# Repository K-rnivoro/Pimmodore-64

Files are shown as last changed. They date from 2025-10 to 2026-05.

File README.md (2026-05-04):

pimmodore small

## A sleek solution for mounting a Raspberry Pi 3B within a Commodore 64 chassis to run emulators or alternative operating systems.

Pimmodore-64 uses the [Keymmodore-64](https://github.com/K-rnivoro/Keymmodore-64) keyboard interface (Pi Pico) so the keyboard is 100% functional. It's a perfect setup for running [BMC64](https://accentual.com/bmc64/), THE Commodore emulator for the Raspberry Pi 3 (any VICE version works well too). 
Functionally speaking, it's like running an original C-64... or C-128, or Plus/4, or PET Graphics, or PET Business. Keyboard will reconfigure itself, allowing you to access all keys, for ANY of the emulated computers.

Also runs perfectly with any Raspberry Pi Operative System, due to having a PC Compatible layout too.

There is also a [modified version of BMC64](https://github.com/slagoela/bmc64) made by Sergio Lagoela, able to automatically switch the Compatibility Mode according the computer being emulated, including the color of the RGB LED.

foto Pimmodore small

Detalle_trasero-removebg-preview

detalle_costado-removebg-preview



To build a Pimmodore-64, you need:

- Build a [Keymmodore-64](https://github.com/K-rnivoro/Keymmodore-64) interface first, including the RGB LED.
- A Raspberry Pi 3B o 3B+.
- A MicroSD Card.
- Any power supply greater than 6VDC, with 15 Watts minimum.
- A Step-down Power converter
- Panel Barrel connector
- Rocker switch
- 2 Joysticks connectors (male DB-9)
- Male 4-pole 3.5mm plug, male RCA and female stereo 3.5mm plug (optional for analog outputs).
- HDMI extension cable.
- 2 USB extension cables (or you can buy a USB 2.0 PC rear panel extension bracket)
- A 3D Printer or a 3D Printing service.
- Dupont cables and connectors.
- Some screws.

Look for the .xlsx file for the detailed BOM.

## Printing the STL Files

The pieces are designed to fit any version of the legendary "Breadbin" Commodore-64 case. It won't fit a C-64C (I don't have one to design it).
The project is 100% reversible, no need to drill, make holes or even glue. It uses the same mount system designed for the original PCB board.

There are two versions, with and without analog outputs (not everybody wants to use an old CRT TV...).

You can use an analog VGA 4:3 monitor (maybe a CRT one for a nice vintage look), with a HDMI to VGA adapter. Remember to buy an adapter with analog audio output in case you don't wire the Pi's analog outputs. Although you will have to create some custom HDMI modes, as explained in [BMC64 page](https://github.com/randyrossi/bmc64)

All pieces are easy to print with a 0.4mm nozzle and a 0.2 mm layer height. For better results, do not flip the pieces, print them as provided. The .3mf file was made for my Bambulab A1, in case you find it useful.
There is no need for «Everywhere» support if you 3D Printer is able to do good «bridging» (most printers do). Just use "Normal" support and «Only from the buildplate».
The only piece who need "Tree" support is the USB Ports cover, and just because of the top lock arm, not for the square holes.
The Pico holder includes a little support, where the board back edge rests, just trim it before placing in.

## Flashing and connecting the Keymmodore-64 interface Pi Pico, to the Pi 3B.

At my project [Keymmodore-64](https://github.com/K-rnivoro/Keymmodore-64) you can find detailed information of how to set up a Raspberry Pi Pico as C-64 keyboard interface. 

Besides the cable connecting the keyboard and the RGB LED, there are also three wires from the Pico, they are used for sensing what type of computer is BMC64 emulating. With this information, the Pico can switch to the corresponding mode, avoiding the manual switch with the C= and Function Keys. As you can see, these three pins have to be connected to GPIO 9, 10 and 11 of the R-Pi 3B.
This is not mandatory, if you do not connect those three pins, you can always use the manual switching, including the "PC Compatible Mode".

### This autoswitch feature works only with the [modified version of BMC64](https://github.com/slagoela/bmc64) made by Sergio Lagoela, it is not included in the oficial release (at least until now).

## Powering the Raspberry Pi

In order to being "agnostic" to the Power Supply, this project uses a Step Down Power Converter, so you can use almost any Power Brick with more than 6V and 15 Watts, a generic 12VDC with 2A will do.
Of course, you need to regulate the Converter BEFORE plug in it to the Raspberry. 5.2VDC will be OK.
Don't try to use a 5VDC power supply directly, the voltage drop of the connector and switch will result in 4.9VDC or less coming into de Pi, therefore the common yellow ligthing bolt sign will appear, and video and audio stuttering will happen, even with "Raspberry Certified Power Supplies". 
Believe me, avoiding the Converter and using a 5VDC Power Supply is not advisable, unless you connect it directly, with no switch in between.

### Remember: Do not plug your Raspberry Pi until you have regulated the Voltage output to 5.2V first!!!!

## Connecting the Joysticks

Unless you have wired the joysticks ports to the Pico interface as mentioned in the Keymmodore-64 project, you can connect them to the Raspberry Pi GPIO pins.

As explained in the [BMC64 website](https://accentual.com/bmc64/), two Atari-like joysticks are supported by the emulator. Here is the wiring according the documentation:



## Enabling the autoswitching feature

In order to the Pico interface to switch between different modes, you need to connect three wires from the GPIOs Pi to the Pico. The GPIOs to be connected are GPIO 9, 10 and 11, as shown in the Keymmodore readme.

Also, add "enable_pimmodore=1" at the beggining of the cmdline.txt file.

Remember this works only for the modified version of BMC64.

## Connecting the analog video and audio outputs (optional)

The Raspberry Pi 3B includes analog video and stereo audio output. For that you need to wire a 4-pole 3.5mm plug, to a female RCA connector for video, and a miniplug stereo female connector for audio.
BMC64 will output NTSC or PAL-B video standard, according what kind of computer are being emulated.
This is optional. You can use your Pimmodore-64 only with HDMI. There is a .stl version or the frame without the analog outputs for that case. 

Keep in mind, the 4-pole miniplug has this (strange) pinout:



## How to set up BMC64 Emulator:

For running BMC64 with the Pi connected to the Pico, you'll need the microSD card with:

1 - The BMC64 Emulator. You can use the modified or the standard BMC64 version, however as explained before, the autoswitching Mode feature won't work in the standard version.

2 - The Kernal ROMs. These are not included in the standard version of BMC64. However you can download from the VICE repository.

3 - The .vkm files in order to have a fully working Keyboard matching all 8-bit emulated computers. Replace the original "positional" .vkm with the new ones.

4 - Enter BMC64 Menu (as explained below), go to "Keyboard" and and change from "Symbolic" to "Positional".

5 - Go to GPIO and check Config is set in "#1 (Nav+Joy)".

6 - Go to Joysticks Menu. If you have wired the joystick ports to the Pi's GPIOs, go to "Joyport" and select GPIO Bank 1 and GPIO Bank 2 for Port 1 and Port 2 respectively. If you have wired the ports to the Pico instead, select Keyset 1 and Keyset 2 and then configure those Keysets below in the same menu.

I strongly recommend to read the [BMC64 readme](https://github.com/randyrossi/bmc64/blob/master/README.md) file for a good understanding of the BMC64 options.

In order to make the whole process easier, I've uploaded a complete version of Lagoela's BMC64 V4.2 autoswitching version, already configured, including the Kernal ROMS and the .vkm files. Joysticks are set as Pi's GPIOs.

I've added HDMI modes for 1080p (HD) monitors and TVs. Both 60Hz for NTSC emulation, and 50 Hz for PAL emulation. I can't tell for every monitor or TV to work OK with 50 Hz, mostly in NTSC-only regions.

Just download, unzip, copy to a FAT32 formatted microSD and boot. 

### Entering the BMC64 Emulator Menu

For entering the BMC64 Menu you need to press CTRL+F7. In PC Compatible Mode (green LED) just press those keys. However, once you are in any Emulator Mode, you can press C= and F7 key for entering the Menu. While browsing the Menu, press Left Arrow Key to go back or exit the Menu. Remember to save the changes before exiting. 

## How to test your keyboard and Joysticks.

I strongly suggest you to use the [Anykey program by T-Pau](https://github.com/T-Pau/Anykey). It has separate versions of programs for every 8 bit Commodore Computer. Very useful. 

## Manual (en español).

I've written a short manual in spanish you can find useful to print (or translate).

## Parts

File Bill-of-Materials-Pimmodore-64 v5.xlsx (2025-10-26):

Description | Item | Quantity | Comments | Suggested Link
Raspberry Pi and SD Memory Card | Raspberry Pi 3B o 3B+ | 1 | R-Pi 3A+, 4 and 5 are not compatible
 | MicroSD 8GB o bigger | 1 | You can buy any MicroSD (compatible with R-Pi)
Keyboard interface | Raspberry Pi Pico (Pins not soldered) | 1 | No need for Pico W, no WiFi suppported | https://www.amazon.com/Raspberry-Pi-Pico/dp/B09KVB8LVR?s=electronics&sbo=RZvfv%2F%2FHxDF%2BO5021pAnSA%3D%3D
 | Male Header 40 Pins Strip (10pcs) | 2 | If not provided with the Board | https://www.amazon.com/MCIGICM-Header-2-45mm-Arduino-Connector/dp/B07PKKY8BX?s=electronics
 | USB-A to Micro-USB Cable | 1 | Generally provided with the Board | https://www.amazon.com/StarTech-com-Mobile-Charge-Micro-Cable/dp/B00MTZUWO8?s=electronics (https://www.amazon.com/gp/product/B00VUIUAN8/ref=ppx_yo_dt_b_asin_title_o02_s04?ie=UTF8&psc=1)
Connectors for Atari/Commodore Joysticks (x2) | Panel mount DB-9 male connectors | 2 |  | https://www.amazon.com/Computer-Connector-Adapter-Connectors-Accessories/dp/B07BQHMKG2?s=electronics
Cables to connect Joysticks ports | Female to female Dupont Cables (40cm) | 1 |  | https://www.amazon.com/EDGELEC-Breadboard-1pin-1pin-Connector-Multicolored/dp/B07GD312VG?s=industrial
RGB LED | RGB translucid LED common anode (do not buy transparent, the effect won't be the same) | 1 | Replaces the original red LED of the C-64 | https://www.amazon.com/EDGELEC-Tri-Color-Multicolor-Diffused-Resistors/dp/B077XD5T8P
 | LED Holder (in case your original holder broke) | 1 |  | https://www.amazon.com/Honbay-Pieces-Plastic-Mounting-Holders/dp/B01LX8JVG7?s=hi
 | Resistor 10KOhms 1/4 Watt | 4 |  | https://www.amazon.com/DIYElectronic-100pcs-Resistor-Tolerance-Precision/dp/B085HNCSS2?s=electronics
Power Supply | Monopole Switch KCD11 (15x21mm) | 1 | Any 15x21 rocker switch (not 10x15 !!!) | https://www.amazon.com/dp/B07Y1GDRQG?tag=picclick0f-20&linkCode=osi&th=1&psc=1
 | Panel mount Barrel Jack Female Connector 5.5x2.1 (same diameter than PS) | 1 | Match Barrel jack diameter of male and female | https://www.amazon.com/MEETOOT-5-5mm-Female-Socket-Electrical/dp/B09JP19XKP
 | Power Supply 12 Volt 4A (with barrel jack connector) | 1 | Any PS with voltage larger than 5V and 15 W should be enough | https://www.amazon.com/Universal-Converter-Transformer-100-240v-5-5x2-5mm/dp/B0D7L6942H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
 | Micro USB Male Plug Cable 30cm | 1 | You can solder a cable to the solder pads of the R-Pi Micro-USB instead | amazon.com/5-5x2-1mm-Converter-Transformer-Surveillance-External/dp/B07GFFG1BQ/ref=sr_1_1_sspa?crid=3UDEQMWS0KRR&dib=eyJ2IjoiMSJ9.Jy4yLGlsxsQ4j2ruSPPP8sdGo7_MV8C27PGwQ5XaYyEBErkYJvKLfZZ7UJ7MP0FWe_UaMuDnNnGXSPtg6wWL7ohDcMkxkhlv5GtmMD71MzzAONcIz2AFMGybRUSKaYgY0Y9KSNYj8d48Psf6un8UmwB007EnYF5RpTr4eAnhMsge7wbBooHIzdoKAiGypMEVLWQ2Jy3-6b08VHExzoYgdxnmD9qh2RuqkQguvAqEjMM.FiBuLPDYSJGmZFBYhS1RPDbl4WgnXozUFemd2zVKEag&dib_tag=se&keywords=12V+Power+Supply+5.5x2.1mm&qid=1761494423&sprefix=12v+power+supply+5.5x2.1mm%2Caps%2C266&sr=8-1-spons&sp_csd=d2lkZ2V0TmFtZT1zcF9hdGY&psc=1
 | Step Down converter | 1 | Adjust output to 5.2V BEFORE connecting it to the R-PI | https://www.amazon.com/XL4005-Adjustable-Supply-Lithium-Charger/dp/B093L9Y6G6?s=electronics
USB Panel Mount extension cables (x2) | Panel Mount USB extension cables (40mm or larger) | 2 | Only panel mount cables | https://www.amazon.com/StarTech-com-USBPNLAFAM2-Extension-Female-Adapter/dp/B00MOENR78?s=electronics
HDMI extension cable. | Panel mount HDMI Cable (1ft) | 1 | If not this model, use alternate (universal) 3D Cover | https://www.amazon.com/gp/product/B01MXD15TE/ref=ppx_yo_dt_b_asin_title_o04_s02?ie=UTF8&psc=1
Optional Analog Video (Composite) and Audio (stereo) Outputs | Four pole male Miniplug 3.5mm | 1 | Only 4 pole miniplug connectors | https://www.amazon.com/gp/product/B077XVDQ5R/ref=ppx_yo_dt_b_asin_title_o04_s02?ie=UTF8&psc=1
 | Panel mount female Miniplug 3.5mm stereo | 1 |  | https://www.amazon.com/gp/product/B01C773OP6/ref=ppx_yo_dt_b_asin_title_o00_s02?ie=UTF8&psc=1
 | Panel mount RCA female connector | 1 |  | https://www.amazon.com/Conwork-Connector-Chassis-Amplifier-Terminal/dp/B07DB36TY9?s=electronics

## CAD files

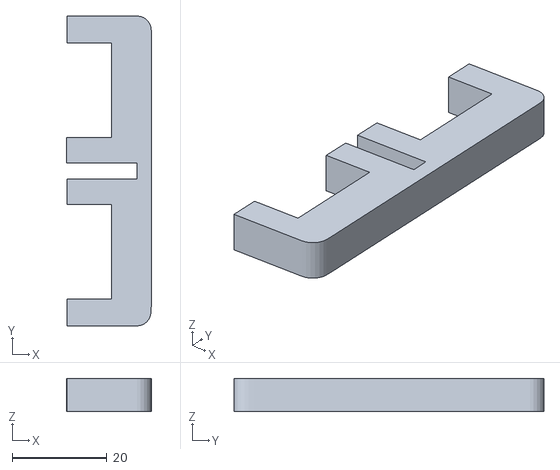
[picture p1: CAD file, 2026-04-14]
STL Files/Pimmodore v45 Joystick ports retainer.stl
17.8 x 65.3 x 7.00

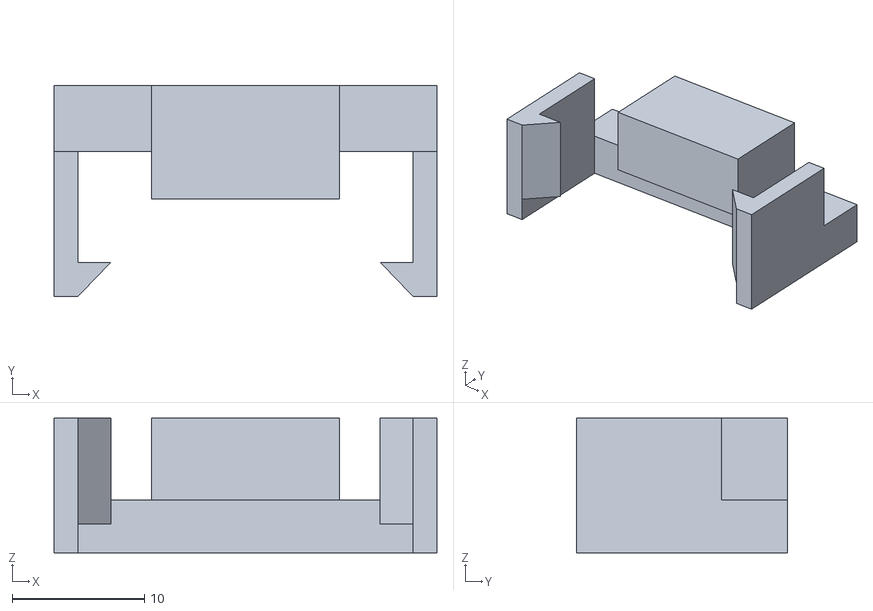
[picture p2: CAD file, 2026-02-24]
STL Files/Pimmodore v45 Pico retainer.stl
29.0 x 16.0 x 10.2

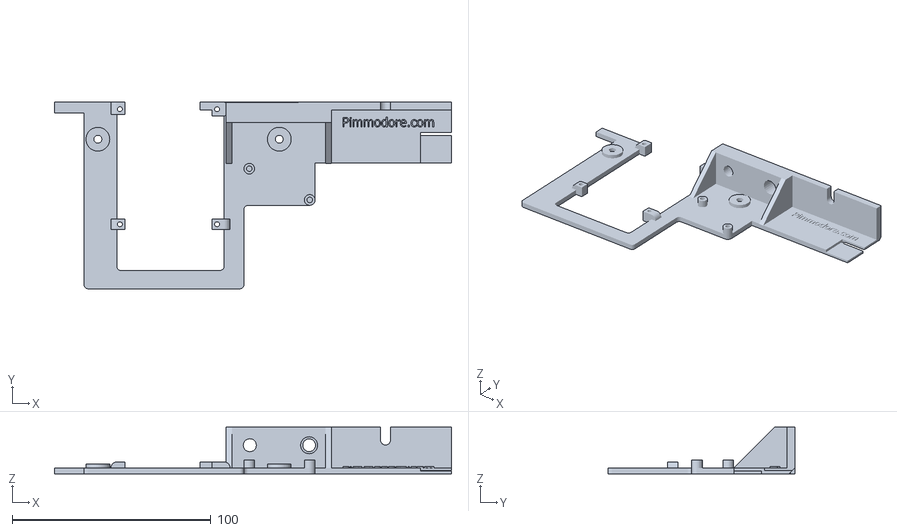
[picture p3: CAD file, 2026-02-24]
STL Files/Pimmodore v45 left frame with analog outputs.stl
200.0 x 94.0 x 23.5

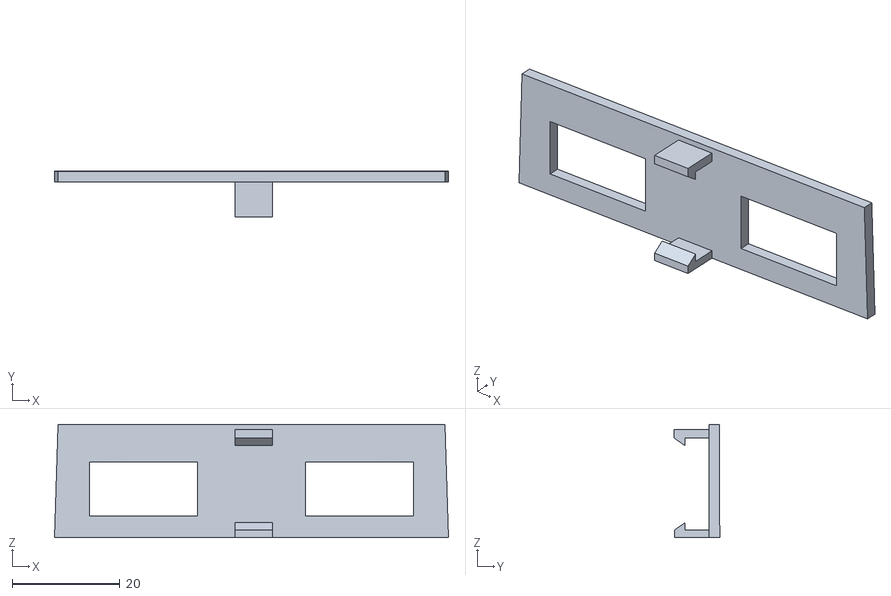
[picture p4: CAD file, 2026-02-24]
STL Files/Pimmodore v45 USB Cover.stl
73.0 x 8.44 x 21.0

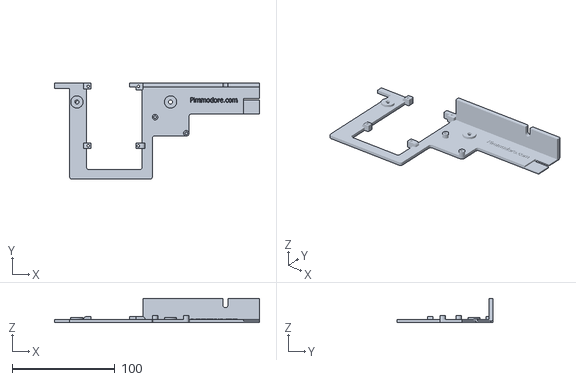
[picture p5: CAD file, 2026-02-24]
STL Files/Pimmodore v45 left frame without analog outputs.stl
200.0 x 94.0 x 23.5

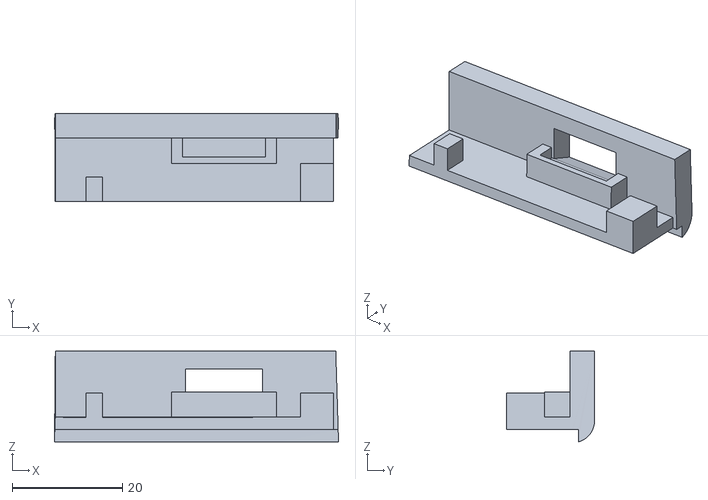
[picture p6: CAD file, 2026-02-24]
STL Files/Pimmodore v45 SD Card.stl
51.5 x 16.0 x 16.5

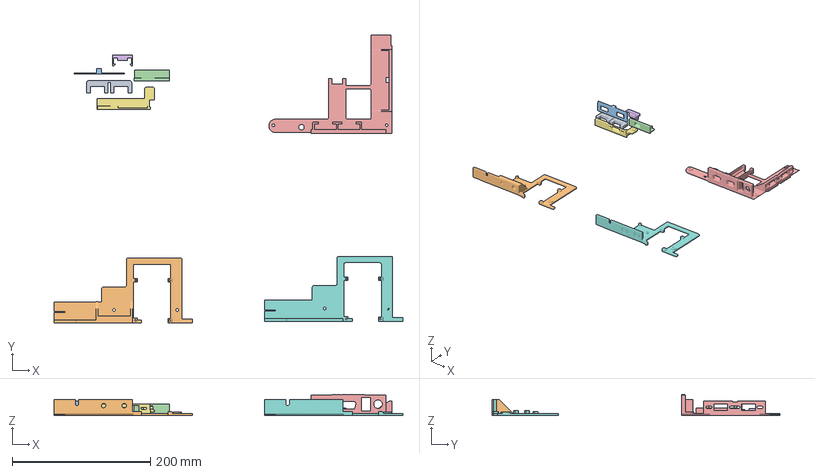
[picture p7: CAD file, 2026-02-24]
STL Files/Pimmodore.3mf
504.5 x 416.1 x 30.6 mm
Pimmodore v45 joystick port retainer.stl
Pimmodore v45 left frame with analog outputs.stl
Pimmodore v45 USB Cover.stl
Pimmodore v45 SD Card.stl
Pimmodore v45 right frame for Pico.stl
Pimmodore v45 Pico retainer.stl
Pimmodore v45 HDMI generic.stl
Pimmodore v45 left frame without analog outputs.stl

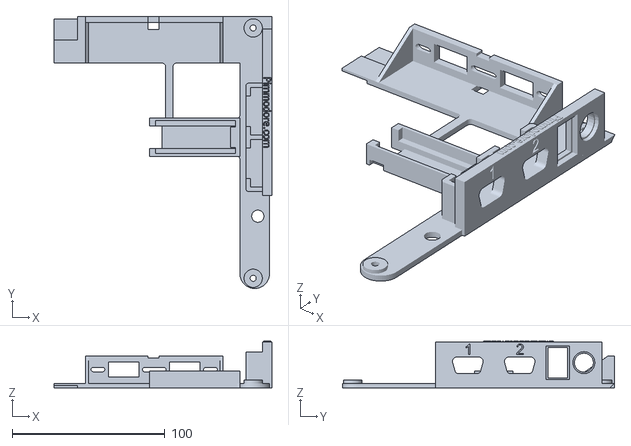
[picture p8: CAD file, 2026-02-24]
STL Files/Pimmodore v45 right frame for Pico.stl
142.4 x 178.0 x 30.6

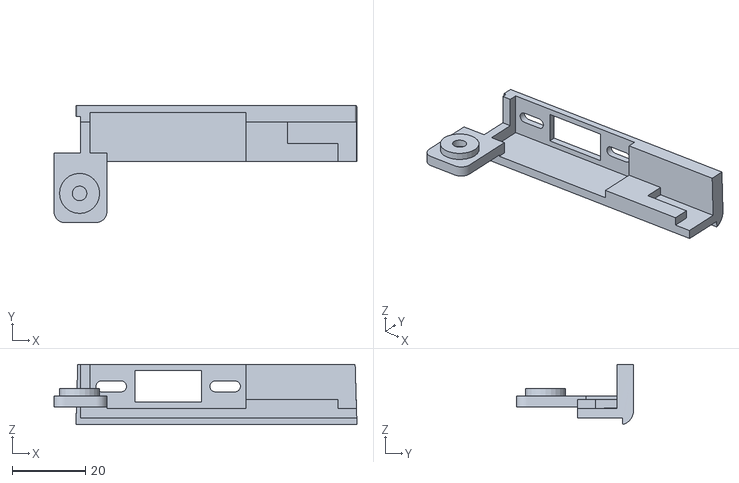
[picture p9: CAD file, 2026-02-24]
STL Files/Pimmodore v45 HDMI generic.stl
83.0 x 32.1 x 16.5

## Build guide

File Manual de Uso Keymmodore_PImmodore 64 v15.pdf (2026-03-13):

www.pimmodore.com

www.pimmodore.com | 2

## Pimmodore-64 y el emulador Bare Metal Commodore 64

El desarrollo Pimmodore-64 está basado en el emulador “Bare Metal Commodore-64” (BMC64) desarrollado por Randy Rossi (https://accentual.com/bmc64/) para la Raspberry Pi 3. Es capaz de emular varias máquinas Commodore de 8 bits: VIC-20, C-64, C-128, la serie C-264 (como la Plus/4 y C-16) y PET (tanto con teclado Graphics como Professional). Además es capaz de emular cada una de ellas tanto en sus versiones NTSC como PAL-B.

Gracias a la colaboración de Sergio Lagoela, existe una versión customizada del BMC64 para la Pimmodore-64, que agrega una funcionalidad que realiza el cambio automático del Modo del Teclado, como se verá mas adelante. Mas información de dicha versión aquí: https://github.com/slagoela/bmc64.

Pimmodore-64 es en realidad, un derivado de la interfase “Keymmodore-64”, la cual convierte el teclado de nuestra C-64 en un teclado USB que pueda ser usado por cualquier computadora o host compatible con dicha norma. Para eso se utiliza una placa Raspberry Pi Pico (no confundir con la Raspberry Pi 3) con una versión personalizada del firmware “Quantum Mechanical Keyboard” (QMK), muy utilizado en teclados gamers.

## Detalle técnico y uso de archivos de configuración “.vkm” para la

emulación.

Pimmodore-64 (o mas bien Keymmodore-64), se basa en dos acciones que son transparentes al usuario:

1. El remapeo del teclado para cada Modo de Compatibilidad de cada una de las maquinas a emular, esto se hace cada vez que se selecciona un Modo de Compatibilidad particular, que se encuentra indicado por el color del LED.
2. La interpretación o conversión de un teclado físico al teclado real de la computadora a emular, lo cual se realiza a través de los archivos “.vkm” con los que cuentan los emuladores basados en VICE (como BMC64 y Combian). Esto lo realiza automáticamente el emulador para cada máquina a emular, leyendo el “.vkm” asociado a dicha máquina.

Es importante entonces, que el emulador a utilizar se encuentre correctamente configurado, y con los archivos “.vkm” correspondientes para cada computadora a emular.

## Emulación de diferentes modelos de computadoras de 8 bits de

Commodore.

Pimmodore-64 es capaz de emular 6 tipos diferentes de computadoras Commodore de 8 bits, a saber:

- Commodore-64.
- Commodore VIC-20.
- Commodore línea 264: Commodore Plus/4, Commodore-16 y Commodore 116.
- Commodore-128.
- Commodore PET Graphics.
- Commodore PET Business.

Además, como se comenta mas adelante, es capaz de utilizarse como un teclado estándar para PC.
Funcionalidad del LED RGB.

Este LED RGB de la Pimmodore-64, le informará que tipo de computadora está siendo emulada, a saber:

Modo Commodore-64, VIC-20, C-16, C-116 y Plus/4.
El Modo Commodore-64, VIC-20, Commodore-16, 116 y Plus/4 Compatible, está diseñado para obtener el 100% de compatibilidad en la distribución de teclas que otorgan tanto los Emuladores de Commmodore-64, VIC-20 y la familia de computadoras Commodore 264. El LED quedará encendido en color rojo, excepto al presionar la tecla C= que se volverá blanco.

### Modo Commodore-128

El Modo Commodore-128, tiene la misma funcionalidad para la C-128 y sus variaciones, incluyendo el teclado numérico y las teclas exclusivas del modelo. El LED se quedará encendido en color azul.

Modo Commodore PET Graphics.
El Modo Commodore PET Graphics Compatible otorga la misma compatibilidad para los emuladores de la familia de Commodore PET. En este caso incluye tanto los caracteres como los gráficos PETSCII que incluía el teclado de la primer versión de la PET llamado comúnmente “Graphics”. Los modelos de PET Graphics son los 2000, 3000 y 4000 (sin B). El LED se quedará encendido en color amarillo

Modo Commodore PET Business.
El Modo Commodore PET Business Compatible, hace lo mismo con la posterior versión de teclado de las PET, conocido comúnmente como “Business”, los cuales en vez de caracteres gráficos PETSCII, contaban con letras mayúsculas y minúsculas. Los modelos de PET Business son la 3000B, 4000B y los modelos 8000 que contaban con 80 columnas. El LED se quedará encendido en color violeta.

Modo PC Compatible.
El Modo PC Compatible es el modo en el que la Pimmodore-64 se utiliza cuando no se encuentra ejecutando el emulador BMC64. Es el que permite utilizar el teclado con cualquier Sistema Operativo, sea de Raspberry, PC, Apple e inclusive Android. Funciona como cualquier teclado USB, con una distribución del tipo “Estados Unidos (US)”. Cuando el teclado se encuentra en el Modo PC Compatible, el LED se muestra en color verde.

Modo de Funciones especiales y Conmutación.

En cualquier de los modos, la tecla C=, pasa a ser una tecla de Modificación o Función (Fn). El LED de la Pimmodore-64 tomará un tono blanco indicando que es posible acceder a otras funcionalidades de acuerdo a la computadora que se esté emulando. Además, permite conmutar manualmente entre diferentes modos de compatibilidad como se ve seguidamente.

Conmutación manual de los modos de Compatibilidad.

Si bien Pimmodore-64 integra una funcionalidad para conmutar automáticamente, es posible realizar la conmutación manualmente para cuando se utiliza en un entorno diferente al emulador BMC64.

Para ello, se utiliza la tecla Commodore (C=) en conjunto con las teclas de Función F1 a F5. Al presionar dicha tecla, el LED tomará un color blanco.

En el esquema siguiente puede identificarse las teclas que permiten cambiar los Modos de Compatibilidad.

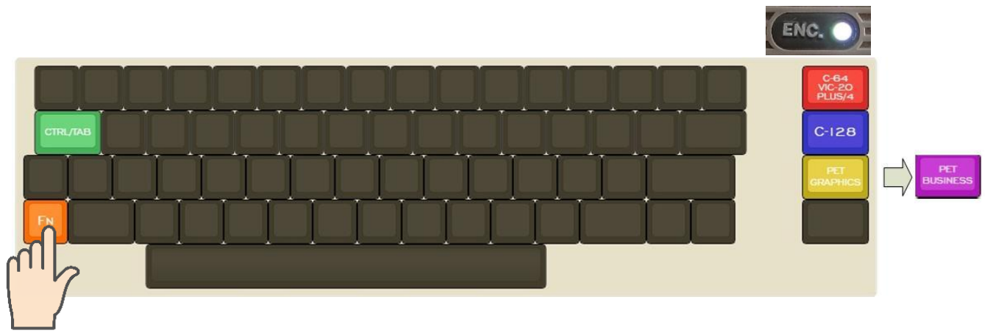
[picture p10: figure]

- Modo C-64, VIC-20, C-16, C-116 y Plus/4: Mantenga presionada la tecla Fn (C=), y presione la tecla F1.
- Modo C-128: Mantenga presionada la tecla C=, y presione la tecla F3.
- Modo PET Graphics: Mantenga presionada la tecla C=, y presione la tecla F5.
- Modo PET Business: Una vez seleccionado el Modo PET Graphics, presione nuevamente la tecla C=, y F5.
- Modo PC: Desde cualquier Modo de los anteriores, presionando C=, y la tecla CONTROL, se vuelve al Modo PC.

Nota importante: Siempre debe volverse al Modo PC primero, antes de cambiar a otro modo. No es posible cambiar entre los diferentes modos de emulación, excepto de PET Graphics a PET Business. Tampoco es posible pasar directamente del Modo PC al PET Business.

## Distribución y funciones de los Modos de Compatibilidad

### Modo compatibilidad con C-64 y VIC-20

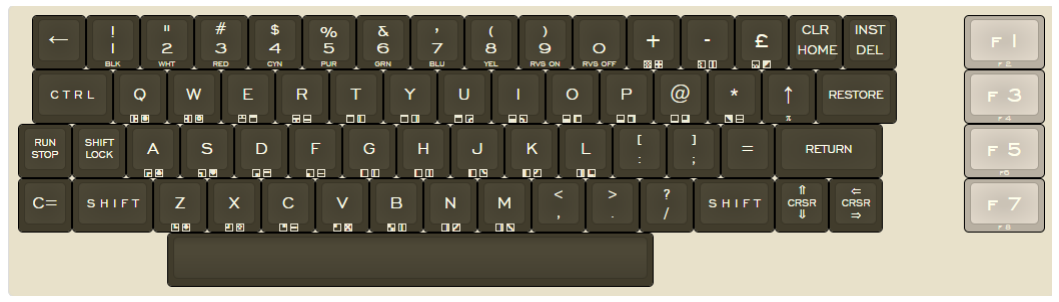
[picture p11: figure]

En este modo, el teclado se comporta exactamente igual que en su equipo original, incluyendo los símbolos sobre el frente de las teclas que se accede presionando SHIFT o C=.

Este modo debe seleccionarse cuando se ejecuta un emulador, para asegurar la compatibilidad total del software que se está ejecutando.

Recordar que para que funcione correctamente, los emuladores deben tener la configuración de teclado en modo “Positional” como se explicó anteriormente.

Se puede volver al Modo compatible con PC, presionando la teclas C= y luego CTRL.

Modo compatibilidad con Plus/4 y C-16.

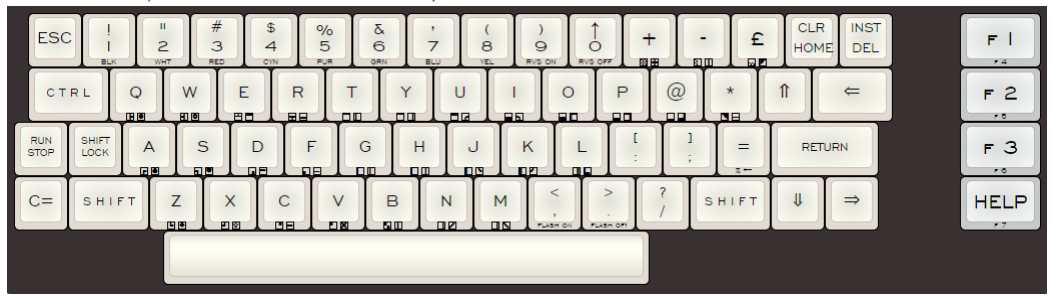
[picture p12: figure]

Si bien los teclados de C-64 y C-16 son físicamente similares, la posición y función de algunas teclas son diferentes, como son las teclas de cursor por ejemplo. Con el objetivo de facilitar su uso, se mantuvo la posición original del teclado de C-64 en aquellas teclas que fuera posible, y se redistribuyeron aquellas diferentes. De esta manera se obtiene la misma funcionalidad que el teclado de C-16 sin tener que recordar su posición original. Los cambios son los siguientes:

- La ubicación de las teclas – (menos), * (asterisco), + (suma), = (igual), £ (pound), y CLEAR/HOME mantienen la posición original de la C-64.
- Se utilizan las teclas originales de cursor de la C-64 para los cursores ↓ (abajo) y → (derecha). A diferencia de la C-64, SHIFT no invertirá la dirección de las mismas.
- Las teclas ↑ y RESTORE funcionan como cursores ↑ (arriba) e (izquierda) respectivamente.
- Las teclas F1, F3, F5 y F7 son F1, F2, F3 y HELP respectivamente, incluyendo el cambio de la funcionalidad a F4, F5, F6 y F7 si se las presiona con SHIFT.

Vale mencionar que tanto en la C-16 como la Plus/4, era necesario presionar las teclas SHIFT o C= para acceder a los caracteres frontales de las teclas (excepto los cursores).

Recordar que para que funcione correctamente, los emuladores deben tener la configuración de teclado en modo “Positional” como se explicó anteriormente.

Presionando la tecla C= junto con CTRL, la distribución vuelve al modo de PC Compatible.

Modo compatibilidad con Commodore-128.

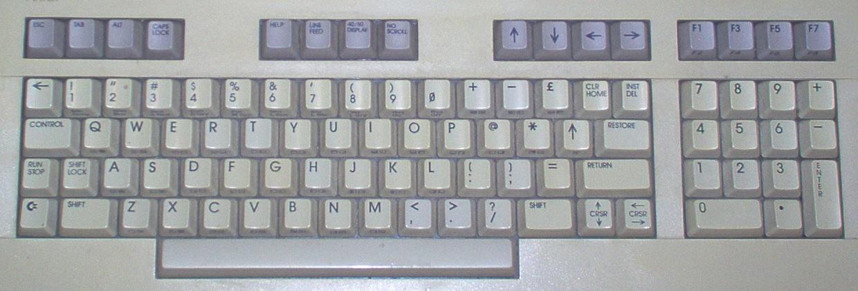
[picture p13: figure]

La C-128 era básicamente un teclado de C-64 ampliado, por lo que la mayoría de sus teclas funcionarán de la misma manera que la C-64.

Teclas especiales de la C-128
Para acceder a las teclas particulares de la C-128 como las de la primera fila y el teclado numérico, se utiliza la tecla de SHIFT Derecho. Al presionarla, el LED se pondrá de color cyan y varias teclas de la Pimmodore se remapean como se muestra en el siguiente esquema.

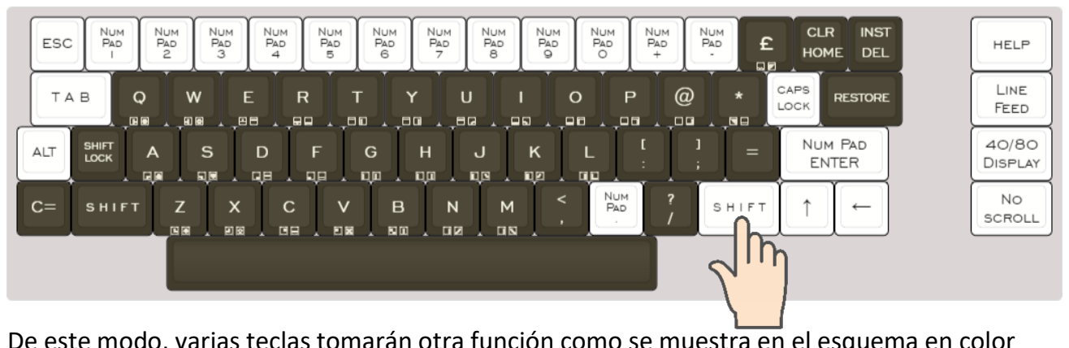
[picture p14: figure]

De este modo, varias teclas tomarán otra función como se muestra en el esquema en color claro.

Por ejemplo, al presionar SHIFT Derecho y las teclas de número, en vez de obtener los signos de puntación de las mismas, obtendrá los números pero que corresponden a las teclas físicas del teclado numérico de la C-128.

Asimismo, podrá acceder a las teclas del teclado numérico, TAB, ALT, CAPS LOCK, etc, las cuales son mapeadas a diferentes teclas como muestra el diagrama.

El resto de las teclas funcionarán indistintamente ya sea con el SHIFT Izquierdo o Derecho.

Recuerde siempre que para salir del Modo C-128 y volver al Modo PC, debe presionar la tecla C= junto con CTRL.

Modo compatibilidad con Commodore PET.
Pimmodore-64 es completamente compatible con la línea de computadoras PET de Commodore. Debe tenerse especial cuidado de que existían dos tipos de teclados de dichas computadoras, la original conocida como teclado “Graphics”, y la posterior con teclado tipo “Business”.

Es importante saber cuales modelos de PET corresponden a cada teclado. En términos generales los modelos 2000, 3000 y 4000 corresponden al teclado Graphics (exceptas aquellas que terminan el B como la 4032B). Los modelos siguientes comenzando por los 8000 con displays de 80 columnas, corresponden a teclados Business.

Como se explicó mas adelante, para utilizar el modo PET Business, primero debe seleccionarse el modo PET Graphics con C= + F5 lo que pondrá el LED color amarillo, luego soltar ambas teclas, y volver a presionar C= + F5 lo que pasará el LED al color violeta indicando el modo PET Business.

Compatibilidad con teclado Graphics.
La distribución de este teclado es completamente diferente a la de Commodore-64. Este teclado presenta la particularidad de tener teclas separadas para los símbolos y para los números, al igual que las teclas de puntuación. Además, cada tecla tiene un solo PETSCII, a diferencia de la C-64 donde casi todas las teclas tienen dos caracteres PETSCII.

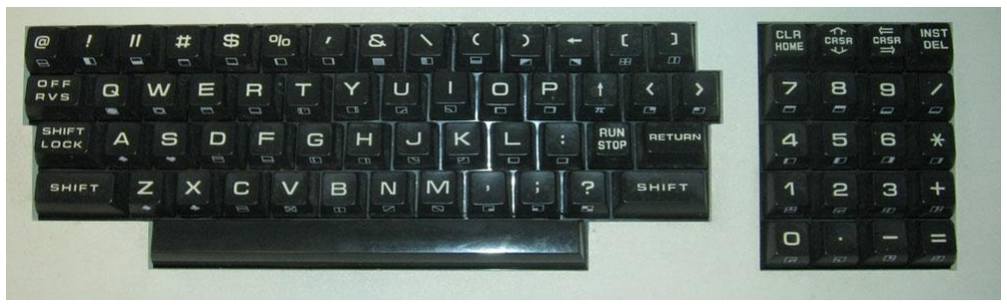
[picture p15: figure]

Se mapean todas las teclas sin perder ninguna funcionalidad, y sin tener que recordar la posición original de ninguna de ellas. En el siguiente esquema se indican en naranja aquellas que cambian de función.

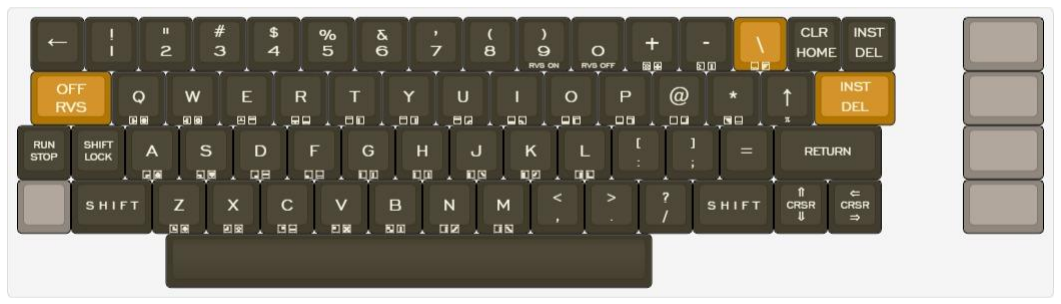
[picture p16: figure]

Las diferencias con el teclado original de PET Graphics son:

- La tecla CTRL pasa a ser OFF/RVS.
- La tecla £ pasa a ser \ (barra invertida).
- La tecla RESTORE funciona como segunda tecla INST/DEL.

- La tecla C= no existen en el teclado PET Graphics, sin embargo la usaremos para acceder a los caracteres gráficos como se explica mas adelante.
- Las teclas de Función (F1 a F8) no existen en el teclado PET Graphics y no tienen asignación (excepto F5 como se ve mas adelante).

Acceso a teclas, funcionalidades y caracteres gráficos PETSCII.
Para poder mantener todas las funciones de cada tecla, Pimmodore-64 implementa una opción que permite acceder tanto a los símbolos como a los caracteres PETSCII de cada una de dichas teclas.

Como se observa en el esquema debajo, con la tecla C= se accede a los símbolos superiores y caracteres ASCII de la izquierda (indicados en verde), y presionando cualquiera de los SHIFT, los que corresponden al color amarillo. Observe que los PETSCII coinciden con los que figuran en el frente de las teclas. Recuerde que cuando presione la tecla C=, el LED se pondrá blanco.

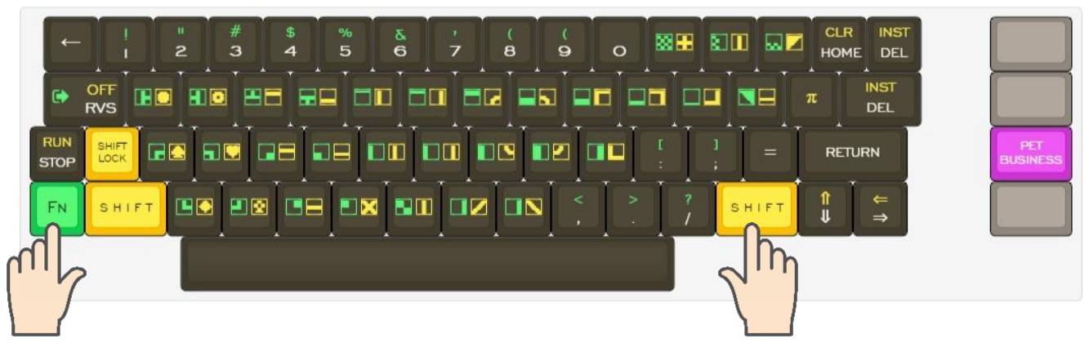
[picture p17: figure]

Nota: Por limitaciones de implementación, esta funcionalidad del Shift Derecho no funciona con las teclas *,@.+.- y \ en el emulador Combian, pero si funcionan con el BMC64.

Compatibilidad con teclado Business.
El teclado Business permite la escritura tanto con mayúsculas como minúsculas y agrega otras nuevas como REPEAT y ESC.

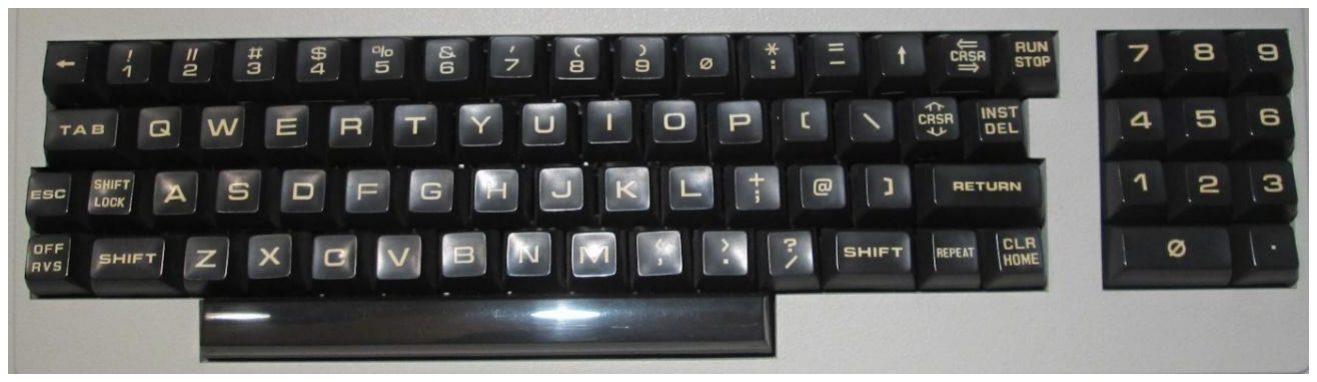
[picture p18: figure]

El mapeo al teclado de C-64 es bastante directo, aunque algunas teclas cambian de posición. Las teclas de Función F1 a F8 y la tecla C= no existen en el teclado PET Business. En el siguiente esquema se resaltan las diferencias:

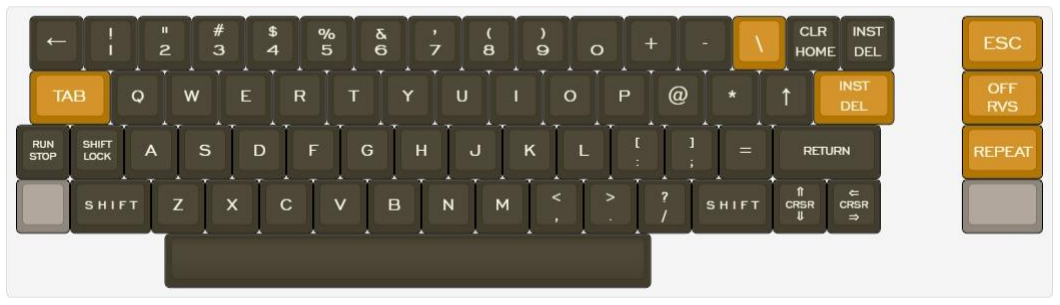
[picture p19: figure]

La tecla CTRL pasa a ser TAB.

La tecla £ pasa a ser \ (barra invertida).

La tecla RESTORE funciona como segunda tecla INST/DEL.

La tecla F1 pasa a ser ESC.

La tecla F3 pasa a ser OFF/RVS.

La tecla F5 pasa a ser REPEAT.

La tecla F7 no tiene asignación, quedando liberada para el uso del Emulador.

La tecla C= funciona como modificador como se vé a continuación.

Acceso a las teclas del Teclado Numérico.
Los modelos PET con teclado Business, tenían doble teclado con números, de manera similar a un teclado moderno, como así también teclas particulares de corchetes y barra invertida ([ ] \). Para acceder con dichas teclas, En caso de ser necesario acceder a dichas teclas, se puede utilizar en combinación con la tecla C=, lo que será indicado con el LED en color blanco.

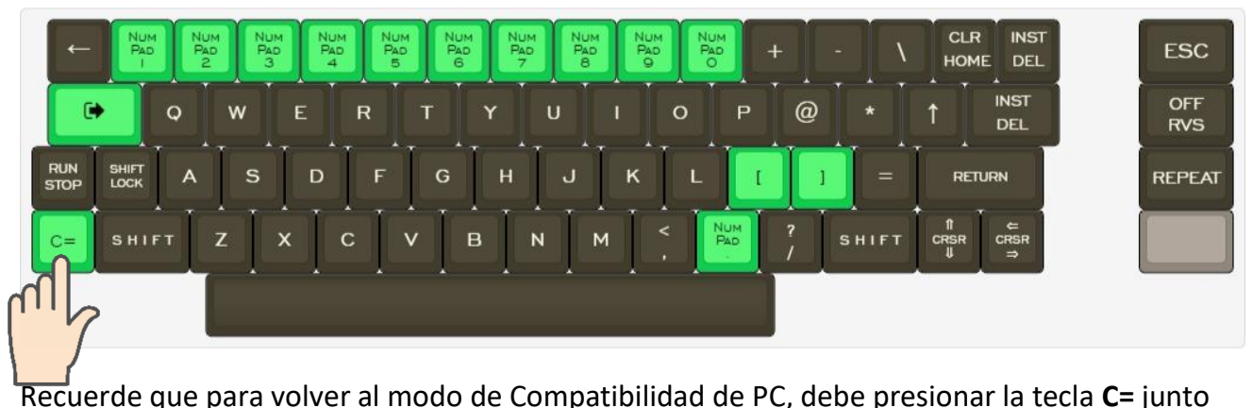
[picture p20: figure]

Recuerde que para volver al modo de Compatibilidad de PC, debe presionar la tecla C= junto con CTRL.

Modo PC Compatible.
El Modo PC Compatible es el modo en el que enciende al conectarlo por USB a cualquier dispositivo diferente a la Raspberry, o cuando la misma no se encuentre ejecutando el BMC64. Cuando la Pimmodore-64 se utiliza con cualquier Sistema Operativo, el teclado funcionará normalmente como un teclado de PC estándar, respetando la distribución original de la C-64 donde sea posible, como así también reutilizando teclas no existentes en teclados actuales de PC.

Debido a su reducido tamaño comparativamente a un teclado estándar, el teclado se comporta de manera similar a los teclados llamados “60%”, donde no existen las teclas de función ni el teclado numérico. Tomando como tecla de acceso de “Función” (Fn) a la tecla marcada con el logo de Commodore (C=), y al Shift Derecho como tecla de “Función 2” (Fn2), es posible acceder al resto de las funcionalidades que no aparecen escritas en el teclado.

En el siguiente esquema se muestra la distribución en Modo PC, remarcando en otro color las teclas que tienen función diferente a la original:

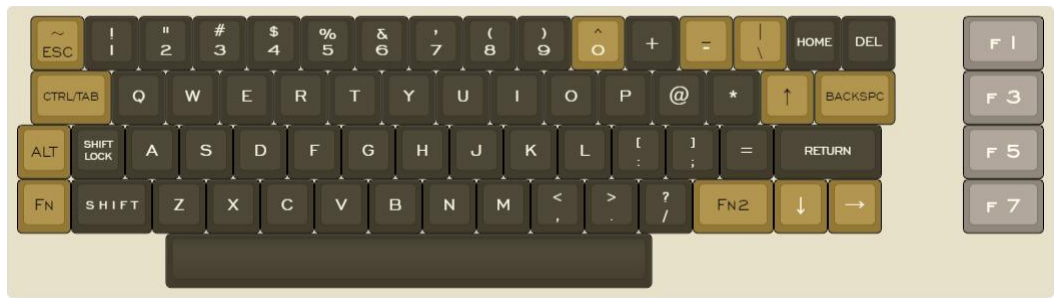
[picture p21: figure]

TECLAS PARTICULARES DE LA C-64.
- RUN/STOP pasa a ser ALT Izquierdo.
- RESTORE pasa a ser BACKSPACE.
- La tecla pasa a ser ESCAPE, o ~ (virgulilla) si se presiona con SHIFT.
- La tecla £ pasa a ser \ (barra invertida), o | (pipe) si se presiona con SHIFT.
- A la tecla 0 se le agrega la función de ^ (acento circunflejo) si se presiona con SHIFT.
- La tecla ↑ desplaza el cursor hacia arriba.
- A la tecla – (menos) se le agrega la función de _ (guión bajo) si se presiona con SHIFT.

El resto de las teclas particulares: @ (arroba), * (asterisco), = (igual) y + (suma), funcionarán como tales, se presionen o no junto con SHIFT.

TECLAS DE CURSOR DE LA C-64.
Las teclas de Cursor (↑/↓) y (/→) funcionarán hacia abajo (↓) y hacia la derecha (→) tal cual lo descripto en las mismas. Si se presionan junto con el Shift Derecho (Fn2), cambian su sentido como se explica mas adelante.

CONTROL IZQUIERDO y TAB EN UNA SOLA TECLA.
Aprovechando que la posición de la tecla CONTROL coincide con la tecla TAB de una PC, Pimmodore-64 implementa un sistema dual para dicha tecla, a saber:

Si se la presiona y suelta normalmente (sin presionar otra tecla), actúa como TAB; sin embargo si se la mantiene presionada y luego se presiona otra tecla, se comporta como CONTROL, permitiendo la combinación con otras teclas, como CTRL+C, CTRL+V, etc.

SHIFT IZQUIERDA y SHIFT LOCK
La tecla de SHIFT Izquierda, funciona de la misma manera que un teclado estándar de PC, permitiendo acceder a las mayúsculas y los caracteres adicionales de acuerdo al esquema visto anteriormente.

La tecla SHIFT LOCK cumple la misma función que el SHIFT Izquierda, agregando una traba mecánica, por lo que vale mencionar que a diferencia del CAPS LOCK estándar, afecta a las teclas 0 a 9 (en vez de los números aparecerán los símbolos).

TECLA COMMODORE (C=) COMO FUNCION ESPECIAL “Fn”
La tecla indicada como C=, llamada generalmente tecla Commodore, funciona como una tecla de modificación Fn que permite acceder a otra capa de funcionalidades dentro del teclado, al igual que los teclados tipo“60%”. Al presionar la misma, el LED se pondrá de color blanco.

En el diagrama siguiente puede verse resaltadas cuales son las teclas que cambiarán su función al presionar Fn. Algunas de estas funcionalidades están inscriptas en las propias teclas y otras se agregan para mayor productividad.

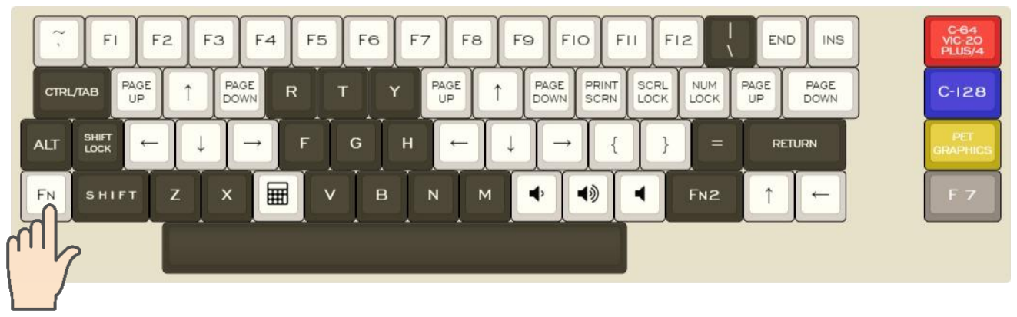
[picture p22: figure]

- Las teclas del 1 al 0, como también + y – pasan a ser las teclas de Función F1 a F12 respectivamente.
- La tecla HOME pasa a ser END.
- La tecla DEL pasa a ser INSERT, como está inscripto en la misma.
- Las teclas ↑ y RESTORE pasan a ser PAGE UP y PAGE DOWN respectivamente.
- Las teclas de Cursor ↓ y → funcionarán hacia arriba (↑) y hacia la izquierda () respectivamente, tal cual lo descripto en parte superior las mismas.
- Las teclas Q y E, al igual que U y O pasan a ser PAGE UP y PAGE DOWN respectivamente.
- Las teclas WASD y IJKL pasan a ser los cuatro cursores direccionales ↑ ↓ y → respectivamente.
- La tecla que era ESCAPE pasa a ser ` (acento grave), y ~ (virgulilla).
- Las teclas : (dos puntos) y ; (punto y coma) pasan a ser { y }(corchetes).
- La tecla P pasa a ser PRINT SCREEN (Captura de Pantalla).
- La tecla @ habilita y deshabilita el SCROLL LOCK.
- La tecla * habilita y deshabilita el NUM LOCK.
- Las teclas < y > bajan y suben el volumen del audio, respectivamente (*).
- La tecla / pone en Silencio (Mute) la salida de audio (*).
- La tecla C inicia la Calculadora (*).

(*) Si es soportado por el sistema operativo.

TECLA SHIFT DERECHA COMO “Fn2”
La tecla de SHIFT Derecha funciona como una tecla de modificación Fn2. Al presionarla, el LED se pondrá de color Cian:

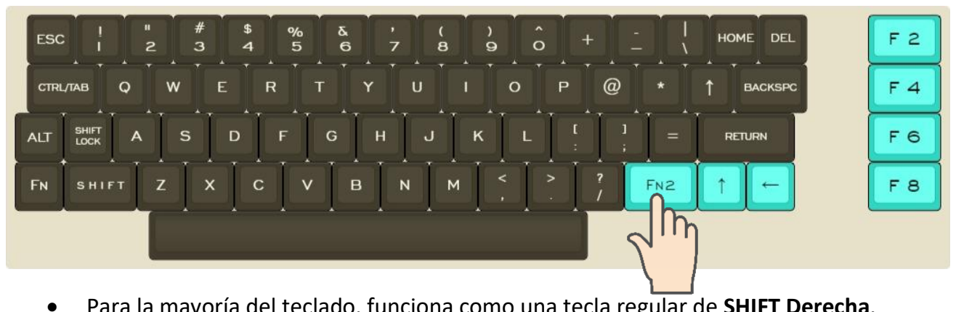
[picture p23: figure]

- Para la mayoría del teclado, funciona como una tecla regular de SHIFT Derecha.
- Las teclas de Cursor ↓ y → funcionarán hacia arriba (↑) y hacia la izquierda () respectivamente, tal cual lo descripto en la parte superior de las mismas.
- Las Teclas de Función pasan a funcionar como F2, F4, F6 y F8. Esta funcionalidad se puede combinar con el SHIFT Izquierdo si por ejemplo quiere presionarse SHIFT + F6 (Puede obtener la misma función presionando C= + SHIFT + 6).
Como navegar el Menú de BMC64.

Para entrar al Menú del emulador BMC64, debe presionar las teclas C= y F7:

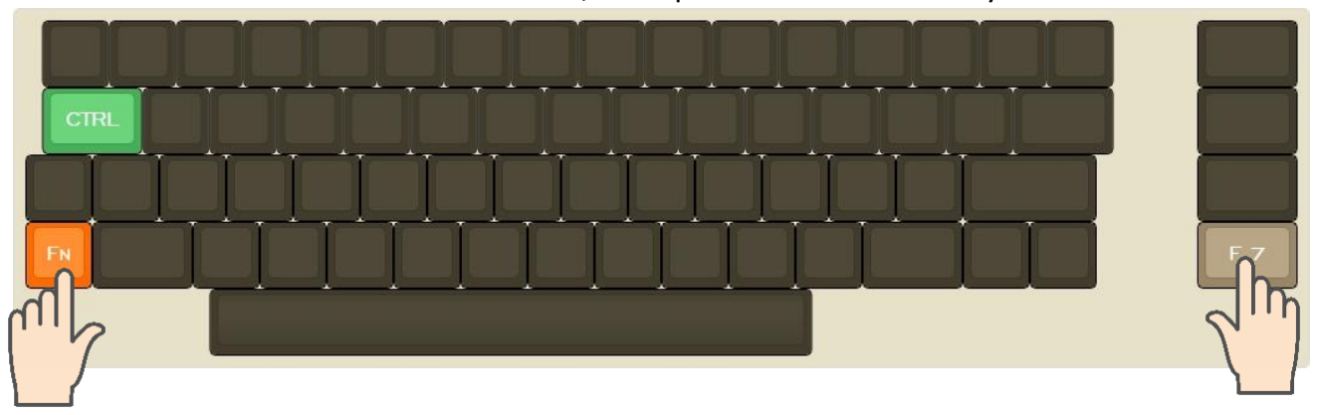
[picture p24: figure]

En caso de que se encuentre en el Modo de Compatibilidad de PC, y desee ingresar al menú, debe presionar CTRL + F7:

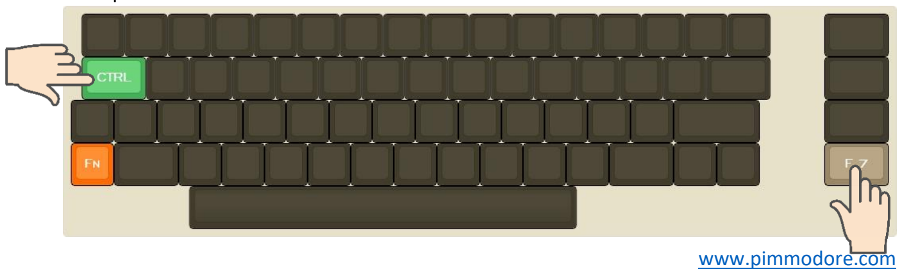
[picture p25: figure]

Al presionar cualquiera de dichas combinaciones, aparecerá el siguiente menú:

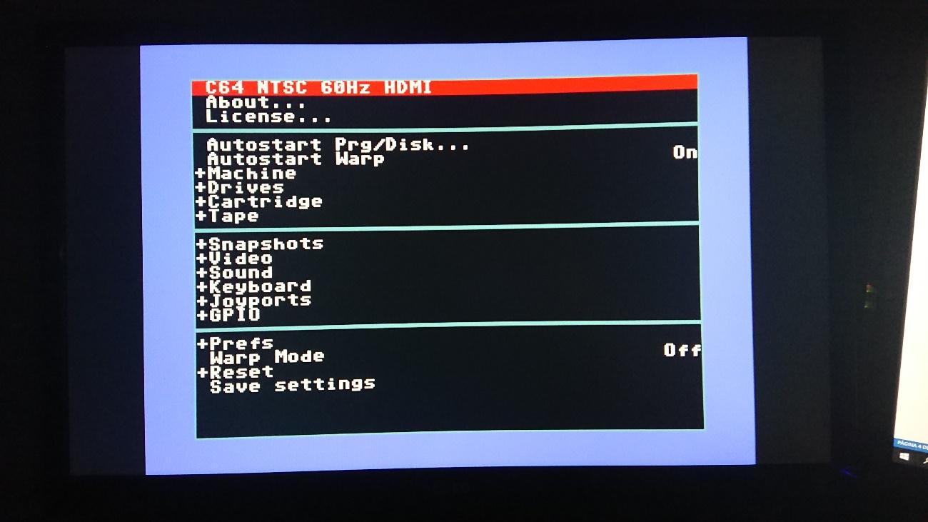
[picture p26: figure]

Al seleccionar un item indicado con + presionando RETURN se ingresa el submenú seleccionado.

Para volver un nivel para atrás, o bien salir del Menú, se debe presionar ESCAPE, lo cual dependerá del modo en el que se encuentre el teclado:
1. Si está en modo PC Compatible: Presionar la tecla que corresponde a ESC.
2. Si está en algún Modo de Compatibilidad de emulación, se debe presionar RUN/STOP que será ESC.

### Configuración del teclado

En el menú +Keyboard es donde se selecciona la distribución del mismo, pudiendo ser “Symbolic” o “Positional”.

Pimmodore-64 utiliza solamente la opción Positional, a través de los archivos “.vkm” creados para tal fin. Verifique para cada máquina, que esta opción se encuentre correctamente configurada.

Como conmutar la maquina a emular.
Para cambiar a otra emulación, hay que entrar al Menú e ir a “Machine/Switch”. Al elegir el modelo de computadora a emular, se abrirá una lista de opciones de acuerdo al tipo de salida de video a utilizar.

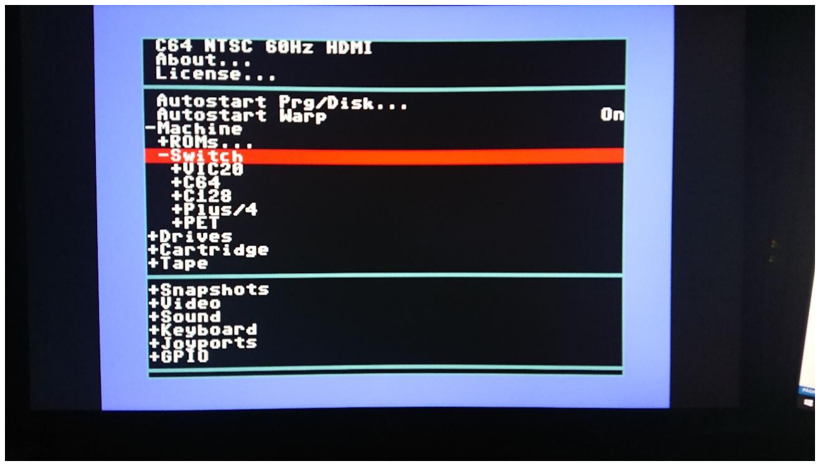
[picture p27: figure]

Para cada máquina a emular, aparecerán opciones tanto para salida digital HDMI, como salida analógica (Composite). Si bien BMC64 mostrará video independientemente de que salida se encuentre conectada, cada modo se encuentra optimizado para un tipo de conexión de video.

No es posible tener ambas salidas (HDMI y Analógico) simultáneamente. BMC64 le dará prioridad al HDMI, y solo en caso de no encontrase dicha conexión, procederá a entregar señal Compuesta (Composite).

Es muy importante aclarar, que no esto no sólo cambia el modo de video, sino que también cambia que tipo de computadora que se está emulando. Los indicados con 50Hz corresponden a las versiones europeas de las máquinas, mientras que las que indican 60Hz corresponden a las versiones estadounidenses o americanas. En términos generales, las versiones europeas suelen tener mayor compatibilidad con el software existente, aunque existe una gran cantidad de juegos y programas que se ejecutan en ambas máquinas.

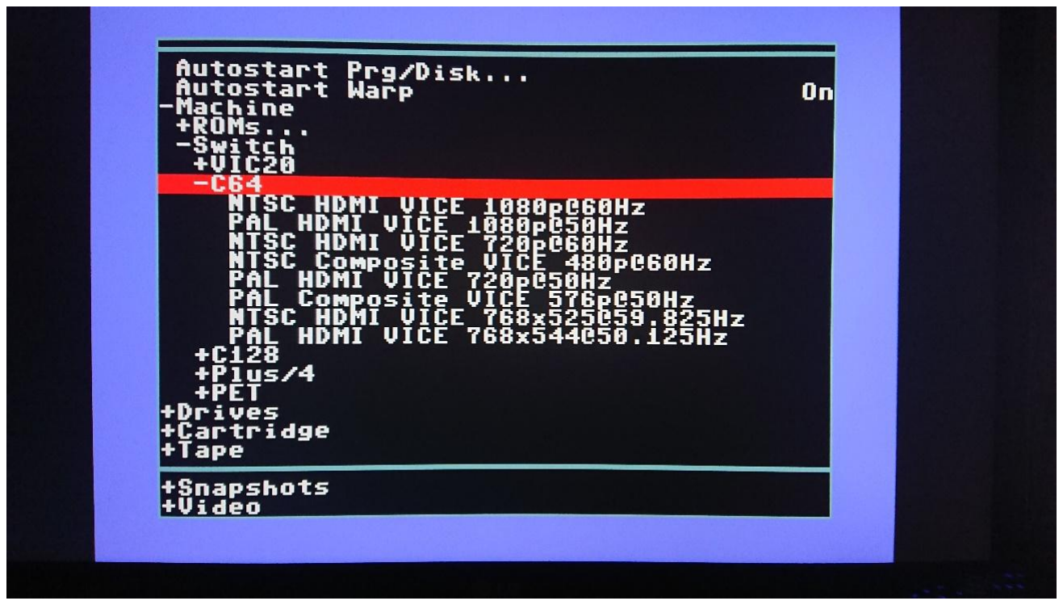
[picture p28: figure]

Para la salida HDMI, se recomienda utilizar los modos “720p“ o “1080p”para la salida HDMI. Los modos “768x” pueden resultar incompatibles con determinados monitores o televisores.

Los modos indicados como “PAL Composite” corresponden a la norma PAL-B, la cual no es compatible con la norma argentina PAL-N. Esto significa que de no contar con un TV que soporte dicha norma, la imagen se verá en blanco y negro. Por otro lado, en general muchos TVs soportan NTSC.

Para el caso particular de las computadoras PET, una vez seleccionado el modelo de PET por default, volviendo a entrar al Menú, aparecerá una opción adicional llamada “Model” donde podrá seleccionar cual modelo quiere emular. Recuerde que existen dos tipos de teclados como se explicó previamente.

### IMPORTANTE: Como recuperarse de un modo de video incompatible

En caso de haber elegido un modo que resulte incompatible con su Televisor, Pimmodore arrancará (el LED se encenderá), pero no tendrá video. Para volver al modo seguro de 720p/50Hz, el emulador BMC64 tiene un atajo:

1. Pase al modo de Compatibilidad con PC, presionando la tecla Commodore (C=) y CONTROL (El LED se iluminará en verde).
2. Presione nuevamente CONTROL y luego F7.
3. Mantenga presionadas ambas teclas por cinco segundos.
4. Suelte la tecla F7 primero, y luego suelte la tecla CONTROL.
5. El LED se apagará y volverá a arrancar en 720p/50Hz.

Optimización de la imagen según la salida: analógica (RCA) o digital (HDMI).
Si bien BMC64 mostrará señal de video siempre, la imagen puede optimizarse o adaptarse para cada caso. Existen muchos parámetros para ajustar, pero dos de los mas importantes son los siguientes:

Scaling Interpolation
Esta funcionalidad permite suavizar la imagen, principalmente los bordes de las letras y gráficos. Para el caso de HDMI, se aconseja dejarla en “On”, pero para el caso de salida analógica, puede dar un resultado mas parecido al original si se pone en “OFF”.

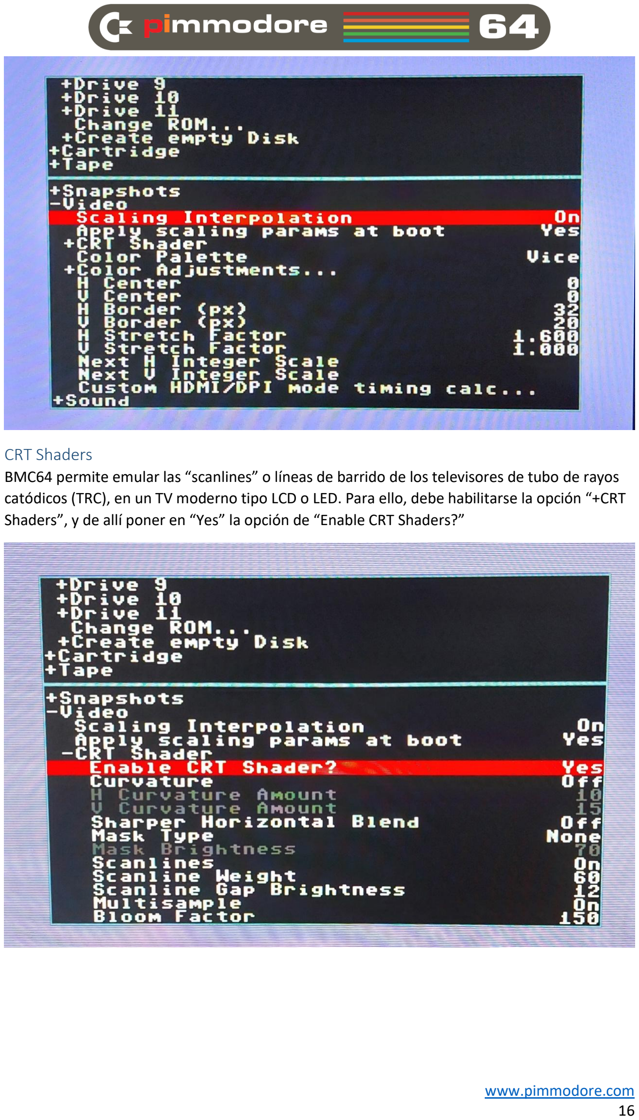
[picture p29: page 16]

CRT Shaders
BMC64 permite emular las “scanlines” o líneas de barrido de los televisores de tubo de rayos catódicos (TRC), en un TV moderno tipo LCD o LED. Para ello, debe habilitarse la opción “+CRT Shaders”, y de allí poner en “Yes” la opción de “Enable CRT Shaders?”

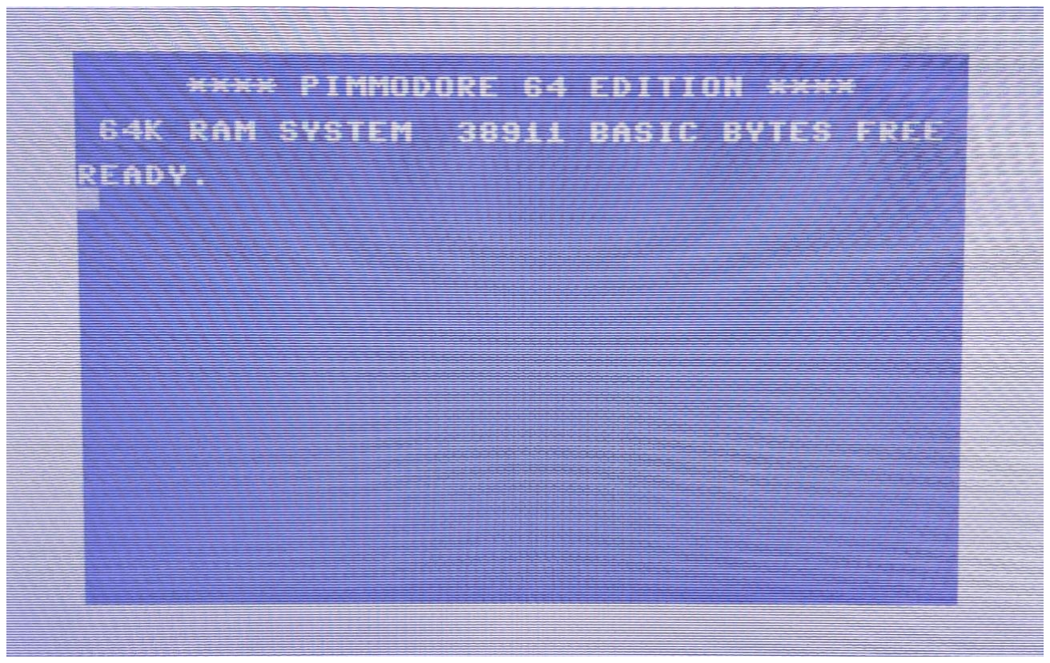
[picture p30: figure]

### Advertencia sobre los cables HDMI

Se recomienda el uso de cables HDMI de buena calidad, y de corta longitud para conectar su Raspberry Pi. Preferiblemente cables con estándar HDMI 2.1 (comúnmente llamados para 4K).

En caso de no tener una salida de video, o que la misma no sea estable, se puede incrementar el nivel de señal de HDMI, editando el archivo “config.txt” que se encuentra en el directorio raíz de la tarjeta SD. Se debe remover el signo “#” del comando “config_hdmi_boost=4” para habilitarlo.

En caso no tener audio por HDMI, verificar también que la línea “hdmi_drive=2” se encuentre también sin el signo “#” adelante.

Configuración de los Joysticks.
Los Joysticks de norma Atari, se encuentra cableados directamente al GPIO de la Rasperry Pi 3. Verifique en la opción de Joyports, que se refieran a dicha configuración tanto para el Port 1 como el Port 2.

Como grabar permanentemente los cambios.
Para que los cambios realizados en la configuración sean permanentes, es necesario ir a “Save Settings” en el menú del BMC

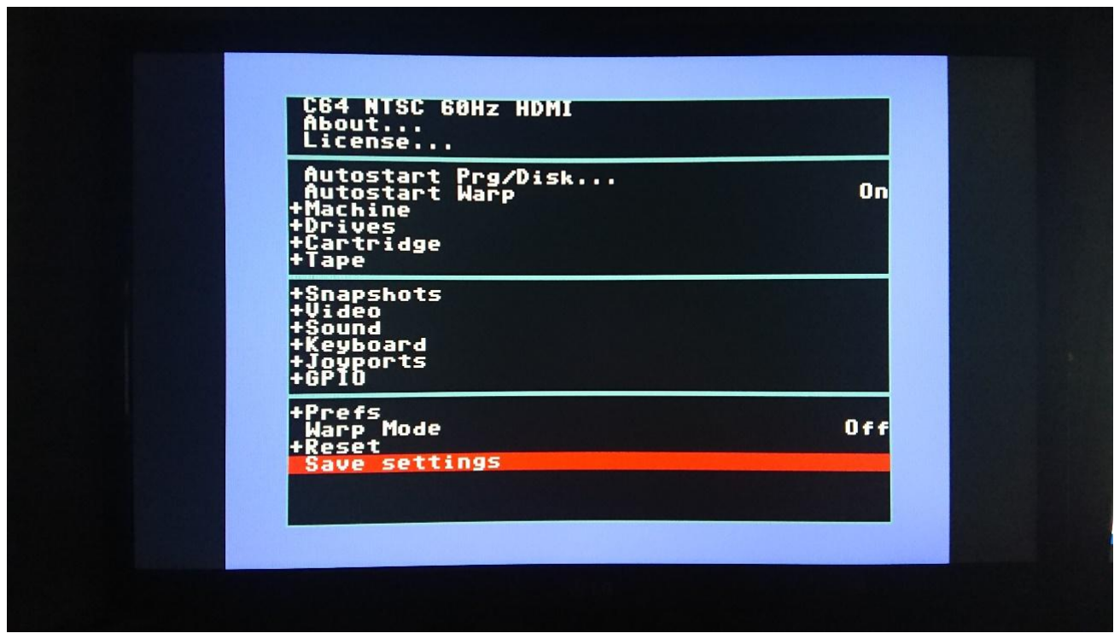
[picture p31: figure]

Como reducir el tiempo de carga de los diskettes.
Para el caso de la emulación de C64, las imágenes .D64 corresponden a diskettes virtuales que son cargados en la disquetera (drive) virtual modelo 1541-II. El BMC emula fielmente los (largos) tiempos de carga que dichas unidades tenían. BMC64 dispone de un modo “Warp” cuando lee los disquetes virtuales, con la intención de reducir dichos tiempos, aunque es no significa que la carga sea instantánea.

Para reducir estas esperas, existen dos opciones:

1. Deshabilitar la función de True Emulation en el menú del BMC. La misma se encuentra en “Drives”. Esto puede hacer algunas cargas incompatibles, por lo que se recomienda utilizarla con cuidado.
2. Utilizar un cartucho virtual tipo “Fast Load”. En la carpeta “Software” puede encontrarse una colección de cartuchos de todo tipo.

## Uso de Pimmodore-64 con otras aplicaciones, emuladores y

sistemas Operativos.

Con solo cambiar la tarjeta SD de nuestra Pimmodore-64, por otra que contenga un sistema operativo como Raspberry Pi OS, o una distribución multiplataformas de juegos como RetroPie o Recalbox, el teclado funcionará perfectamente, al igual que lo haría un teclado normal de PC conectado a la Raspberry Pi. Sólo tiene que conectar un mouse a un puerto USB para el caso de un Sistema Operativo con interfase gráfica.

Pimmodore también puede funcionar con otros emuladores de Commodore como Combian 64 de Carmelo Maiolino (https://cmaiolino.wordpress.com/), aunque no ofrece las mismas prestaciones, ya que a diferencia del BMC64 que es del tipo “Bare Metal”, Combian-64 utiliza una distribución Linux.

Uso del teclado de la C-64 en una PC externa.

Tambien puede desconectar la Raspberry Pi Pico de la Raspberry Pi 3, y conectarla a una PC con un cable USB, la PC lo detectará como un teclado normal. De esa manera se puede utilizar en cualquier PC, inclusive con el emulador VICE.

Nota importante: Para que el teclado funcione correctamente, se debe verificar que en el dispositivo a usar (ya sea plataforma Windows, Linux, Android, etc) la distribución del teclado se encuentre configurada como “Estados Unidos (US)”, o “Estados Unidos - Internacional”. No debe estar configurado como Reino Unido (UK), Español, Latinoamericano o cualquier otra distribución que no sea Estados Unidos (US).

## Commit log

2025-10-24 Add requirement for 3D printer or printing service
2025-10-24 Add Step Down Power converter to requirements
2025-10-26 Revise power supply section in README.md
    Reorganize and clarify power supply recommendations for Raspberry Pi.
2025-10-26 Revise README for clarity on project details
    Updated descriptions for the Commodore-64 project and the Raspberry Pi connection.
2026-02-24 Revise 3D printing guidelines in README
    Updated printing instructions and support requirements for 3D printing components.
2026-02-24 Revise connector details and analog output notes
    Updated connector specifications and clarified optional analog output usage.
2026-04-17 Update USB extension cables description in README
    Clarified the description of USB extension cables.
2026-04-17 Enhance README with compatibility details
    Added information about compatibility with Raspberry Pi operating systems and a modified version of BMC64.
2026-04-17 Fix wiring instructions for Pico interface
2026-04-17 Update README description for Raspberry Pi setup
    Refine description for clarity and conciseness.
2026-10-27 Update README with clearer GPIO and power supply info
    Clarified instructions regarding GPIO connections and power supply requirements.
2026-10-27 Fix grammar in wiring instructions for Pimmodore-64
    Corrected grammar in the README regarding wiring for keyboard mode switching.
2026-10-27 Revise joystick wiring instructions in README
    Updated joystick configuration instructions for GPIO and Pico setups.
2026-10-27 Clarify inclusion of holder for Pico interface
2026-10-27 Update README with design clarifications and details
    Clarified design details for the Commodore-64 case and added information about Pico interface versions.
2026-10-27 Fix wording in case version description
    Corrected 'upper' to 'top' for consistency in case description.
